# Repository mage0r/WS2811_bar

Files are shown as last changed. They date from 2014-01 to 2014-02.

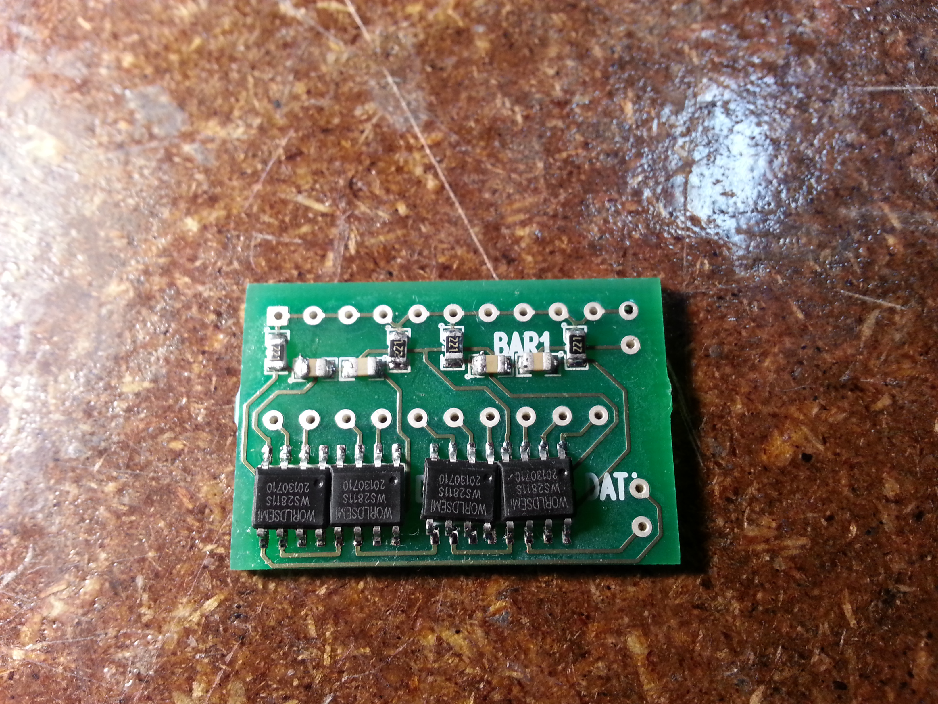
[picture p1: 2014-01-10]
Photos/2014-01-04 15.56.35.jpg

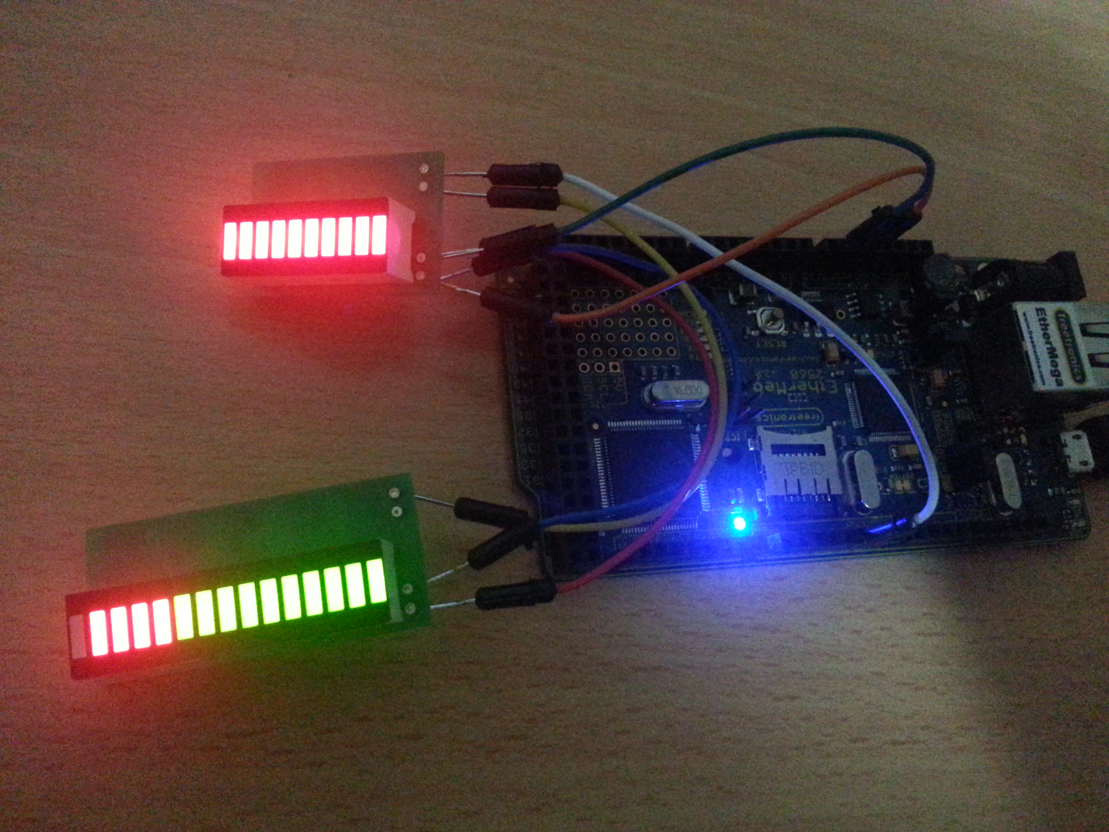
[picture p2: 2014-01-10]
Photos/2014-01-05 21.55.42.jpg

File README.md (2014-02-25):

WS2811_bar
=============

This project drives a LED bar graph using a single pin from your microcontroller.

It is designed around using the popular WS2811 LED driver chip commonly used in the adafruit neopixels.  This also means several bar graphs can be chained together or the bar graph can follow a sequence of WS2811 or WS2812 LED's.

There has three sections, a kicad circuit diagram, an arduino sketch using the neopixel library from adafruit and lastly a few photos of it in action.

Of course, this is a hacky way to use these chips and there are several disadvantages.  Chifely, each chip drives 3 seperate LED's, meaning if you want to iterate through them activating each one, you have to iterate not only through the "pixels" but also through the "colours".

Also, as each chip drives 3 LED's and there are 10 LED's all up, there are two channels "spare", these are the last two of the last pixel.

Depending on the WS2811 chip you use, you may end up with a GRB rather than a RGB.  Just because there wasn't enough confusion already...

Improvements and changes cheerfully accepted.

WS2811_bar 10 digit bar graph controlled by ws2811 chips

WS2811_bar 10 and 15 digit bar graph controlled by ws2811 chips

(https://www.youtube.com/watch?v=YOKhcFke9yQ)

CREDITS
------------
This board was designed by John Spencer - john.spencer.9000@gmail.com - https://github.com/mage0r

SPECIAL THANKS
------------
To the creators and maintainers of the KiCAD open-source EDA suite.
To the HackMelbourne (CCHS, http://hackmelbourne.org) community of Melbourne, Australia. Especially Lachlan Maher, and Bob Powers.
To all other open-source developers whose countless hours supported every other aspect of this design.
Extra thanks to Bob because I copied his README.md almost verbatim...

DISTRIBUTION
------------
The specific terms of distribution of this project are governed by the
license referenced below. Please contact the copyright owner if you wish to modify the board for distribution. Please utilize this design for personal or research projects. Please acknowledge all contributors.

LICENSE
-------
Licensed under the TAPR Open Hardware License (www.tapr.org/OHL).
The "license" sub-folder also contains a copy of this license in plain text format.

Copyright John Spencer 2013
john.spencer.9000@gmail.com

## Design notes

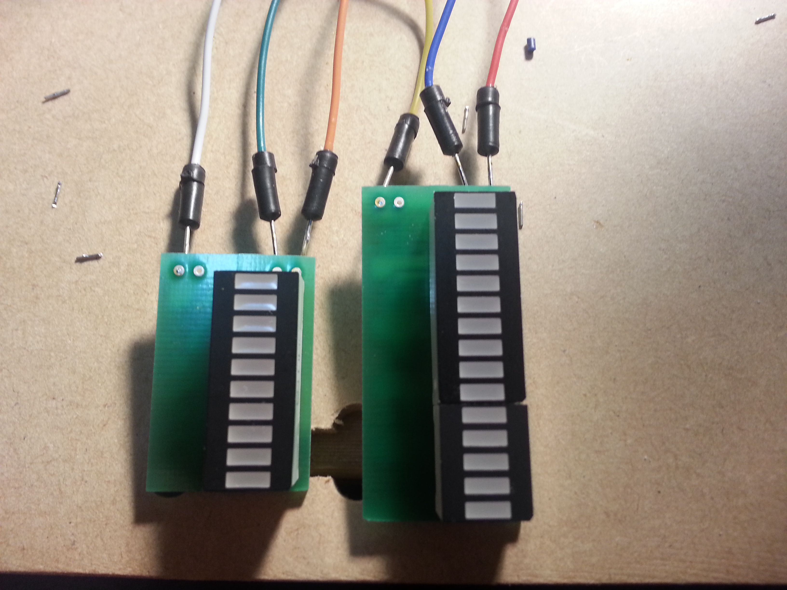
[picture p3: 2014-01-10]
Photos/2014-01-05 21.15.20.jpg

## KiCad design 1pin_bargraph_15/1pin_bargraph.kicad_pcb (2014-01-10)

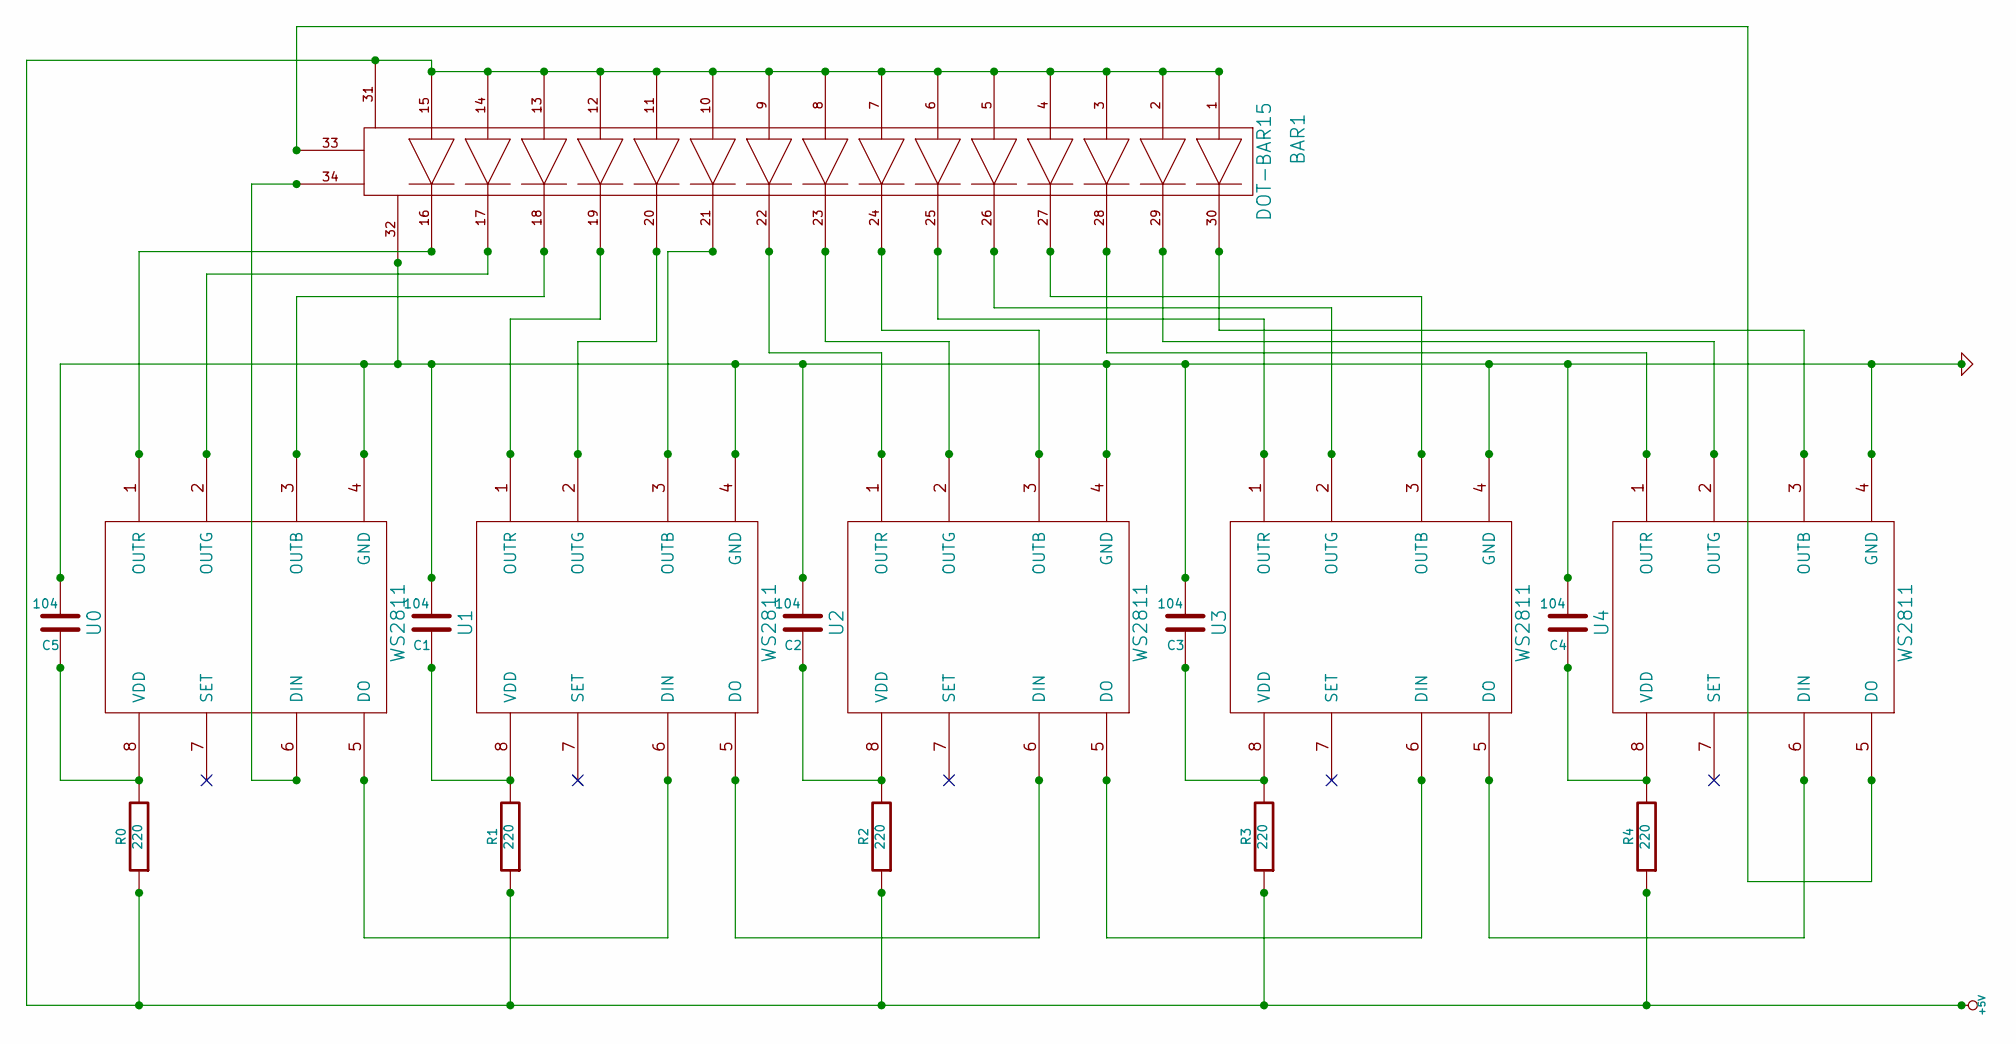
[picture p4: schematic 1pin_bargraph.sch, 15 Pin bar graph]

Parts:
BAR1: DOT-BAR15
C1, C2, C3, C4, C5: 104
R0, R1, R2, R3, R4: 220
U0, U1, U2, U3, U4: WS2811

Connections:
+5V: BAR1.1 (A), BAR1.2 (A), BAR1.3 (A), BAR1.4 (A), BAR1.5 (A), BAR1.6 (A), BAR1.7 (A), BAR1.8 (A), BAR1.9 (A), BAR1.10 (A), BAR1.11 (A), BAR1.12 (A), BAR1.13 (A), BAR1.14 (A), BAR1.15 (A), BAR1.31 (V+), R0.1, R1.1, R2.1, R3.1, R4.1
GND: BAR1.32 (GND), C1.2, C2.2, C3.2, C4.2, C5.2, U0.4 (GND), U1.4 (GND), U2.4 (GND), U3.4 (GND), U4.4 (GND)
unnamed: BAR1.21 (K), U1.3 (OUTB)
unnamed: BAR1.20 (K), U1.2 (OUTG)
unnamed: BAR1.29 (K), U4.2 (OUTG)
unnamed: BAR1.26 (K), U3.2 (OUTG)
unnamed: BAR1.23 (K), U2.2 (OUTG)
unnamed: BAR1.28 (K), U4.1 (OUTR)
unnamed: U2.5 (DO), U3.6 (DIN)
unnamed: C3.1, R3.2, U3.8 (VDD)
unnamed: C4.1, R4.2, U4.8 (VDD)
unnamed: U3.5 (DO), U4.6 (DIN)
unnamed: BAR1.30 (K), U4.3 (OUTB)
unnamed: U1.5 (DO), U2.6 (DIN)
unnamed: U0.5 (DO), U1.6 (DIN)
unnamed: BAR1.33 (DATA), U4.5 (DO)
unnamed: BAR1.34 (DATA), U0.6 (DIN)
unnamed: BAR1.18 (K), U0.3 (OUTB)
unnamed: BAR1.27 (K), U3.3 (OUTB)
unnamed: BAR1.17 (K), U0.2 (OUTG)
unnamed: BAR1.25 (K), U3.1 (OUTR)
unnamed: BAR1.24 (K), U2.3 (OUTB)
unnamed: BAR1.22 (K), U2.1 (OUTR)
unnamed: C1.1, R1.2, U1.8 (VDD)
unnamed: BAR1.16 (K), U0.1 (OUTR)
unnamed: C5.1, R0.2, U0.8 (VDD)
unnamed: C2.1, R2.2, U2.8 (VDD)
unnamed: BAR1.19 (K), U1.1 (OUTR)

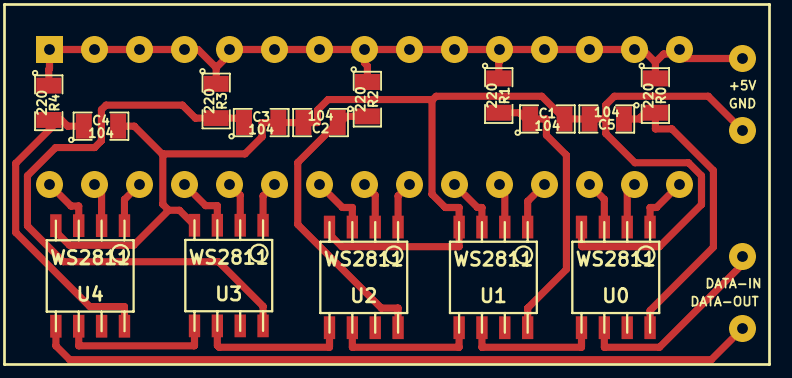
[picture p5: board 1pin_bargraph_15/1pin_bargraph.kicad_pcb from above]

Board: 2 copper layers, 16 parts (0 on the bottom side), 28 nets.

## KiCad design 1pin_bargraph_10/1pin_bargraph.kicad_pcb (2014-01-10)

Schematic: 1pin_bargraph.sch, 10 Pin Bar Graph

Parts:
BAR1: DOT-BAR10-DATA
C1, C2, C3, C5: 104
R0, R1, R2, R3: 220
U0, U1, U2, U3: WS2811

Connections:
+5V: BAR1.1, BAR1.2, BAR1.3, BAR1.4, BAR1.5, BAR1.6, BAR1.7, BAR1.8, BAR1.9, BAR1.10, BAR1.21, R0.1, R1.1, R2.1, R3.1
GND: BAR1.22, C1.2, C2.2, C3.2, C5.2, U0.4 (GND), U1.4 (GND), U2.4 (GND), U3.4 (GND)
unnamed: C3.1, R3.2, U3.8 (VDD)
unnamed: U0.5 (DO), U1.6 (DIN)
unnamed: U1.5 (DO), U2.6 (DIN)
unnamed: U2.5 (DO), U3.6 (DIN)
unnamed: C2.1, R2.2, U2.8 (VDD)
unnamed: BAR1.23, U3.5 (DO)
unnamed: BAR1.18, U2.2 (OUTG)
unnamed: BAR1.24, U0.6 (DIN)
unnamed: BAR1.19, U2.3 (OUTB)
unnamed: BAR1.17, U2.1 (OUTR)
unnamed: BAR1.20, U3.1 (OUTR)
unnamed: BAR1.14, U1.1 (OUTR)
unnamed: BAR1.16, U1.3 (OUTB)
unnamed: C1.1, R1.2, U1.8 (VDD)
unnamed: BAR1.11, U0.1 (OUTR)
unnamed: BAR1.12, U0.2 (OUTG)
unnamed: BAR1.13, U0.3 (OUTB)
unnamed: C5.1, R0.2, U0.8 (VDD)
unnamed: BAR1.15, U1.2 (OUTG)

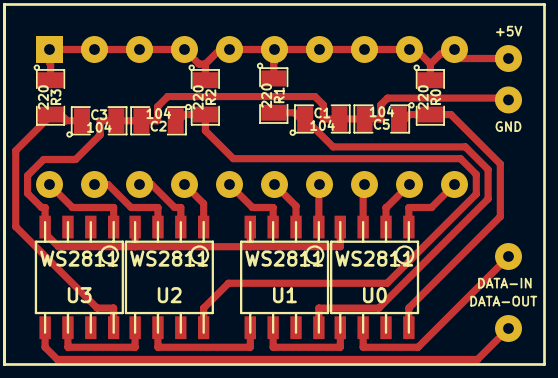
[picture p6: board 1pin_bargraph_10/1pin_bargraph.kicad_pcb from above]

Board: 2 copper layers, 13 parts (0 on the bottom side), 21 nets.

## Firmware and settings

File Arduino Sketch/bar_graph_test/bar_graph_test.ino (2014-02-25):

#include <Adafruit_NeoPixel.h>

// This code uses ws2811b chips to drive a bar graph.
// Just in case it wasn't obvious, this is terrible code :)
// John Spencer - 2014

#define PIN 4

// Parameter 1 = number of pixels in strip
// Parameter 2 = pin number (most are valid)
// Parameter 3 = pixel type flags, add together as needed:
//   NEO_KHZ800  800 KHz bitstream (most NeoPixel products w/WS2812 LEDs)
//   NEO_KHZ400  400 KHz (classic 'v1' (not v2) FLORA pixels, WS2811 drivers)
//   NEO_GRB     Pixels are wired for GRB bitstream (most NeoPixel products)
//   NEO_RGB     Pixels are wired for RGB bitstream (v1 FLORA pixels, not v2)
Adafruit_NeoPixel strip = Adafruit_NeoPixel(15, PIN, NEO_GRB + NEO_KHZ800);

void setup() {
  strip.begin();
  strip.show(); // Initialize all pixels to 'off'
}

void loop() {
  // Some example procedures showing how to display to the pixels:
  //colorWipe(strip.Color(255, 0, 0), 50); // Red
  //colorWipe(strip.Color(0, 255, 0), 50); // Green
  //colorWipe(strip.Color(0, 0, 255), 50); // Blue
  //rainbow(20);
  //rainbowCycle(20);
  
      fillTo(150,500);
}

void fillTo(int percentage, int wait) {
  
  int bars[15][4] = {
                    {0,0,20,0},\
                    {0,20,0,0},\
                    {0,0,0,20},\
                    {1,0,20,0},\
                    {1,20,0,0},\
                    {1,0,0,20},\
                    {2,0,20,0},\
                    {2,20,0,0},\
                    {2,0,0,20},\
                    {3,0,20,0},\
                    {3,20,0,0},\
                    {3,0,0,20},\
                    
                    
                    
                    {4,0,50,0},\
                    {4,50,0,0},\
                    {4,0,0,50},\
                    
                    

                    
                    
                  };
  int previous_bar = 0;
  
  for (int i=0; i<percentage/10; i++){
    if (bars[i][0] != previous_bar)
    {
      //strip.setPixelColor(previous_bar,0);
      //strip.show();

    }
    previous_bar = bars[i][0];
    
    //strip.getPixelColor(bars[i][0]) + ((uint32_t)bars[i][1] << 16) | ((uint32_t)bars[i][2] <<  8) | bars[i][3];
    
    strip.setPixelColor(bars[i][0],strip.getPixelColor(bars[i][0]) + ((uint32_t)bars[i][1] << 16) | ((uint32_t)bars[i][2] <<  8) | bars[i][3]);
    strip.show();
    delay(wait);
  }
  
  //((uint32_t)r << 16) | ((uint32_t)g <<  8) | b;
  
  strip.setPixelColor(0,0);
  strip.setPixelColor(1,0);
  strip.setPixelColor(2,0);
  strip.setPixelColor(3,0);
  
  strip.setPixelColor(4,0);
  strip.setPixelColor(5,0);
  strip.setPixelColor(6,0);
  strip.setPixelColor(7,0);
  strip.setPixelColor(8,0);
  
}

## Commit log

2014-01-10 Initial Commit
    This is a big commit and includes everything except the library and code
    examples.
    [1pin_bargraph.dsn, 1pin_bargraph.kicad_pcb, 1pin_bargraph.sch]
2014-01-10 added images to readme
    Image of the boards in the readme
2014-01-10 Close bracket for link
